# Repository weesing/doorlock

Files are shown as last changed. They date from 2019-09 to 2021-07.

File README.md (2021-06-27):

# Introduction
This project contains the Arduino Lock module program for the Door Lock.
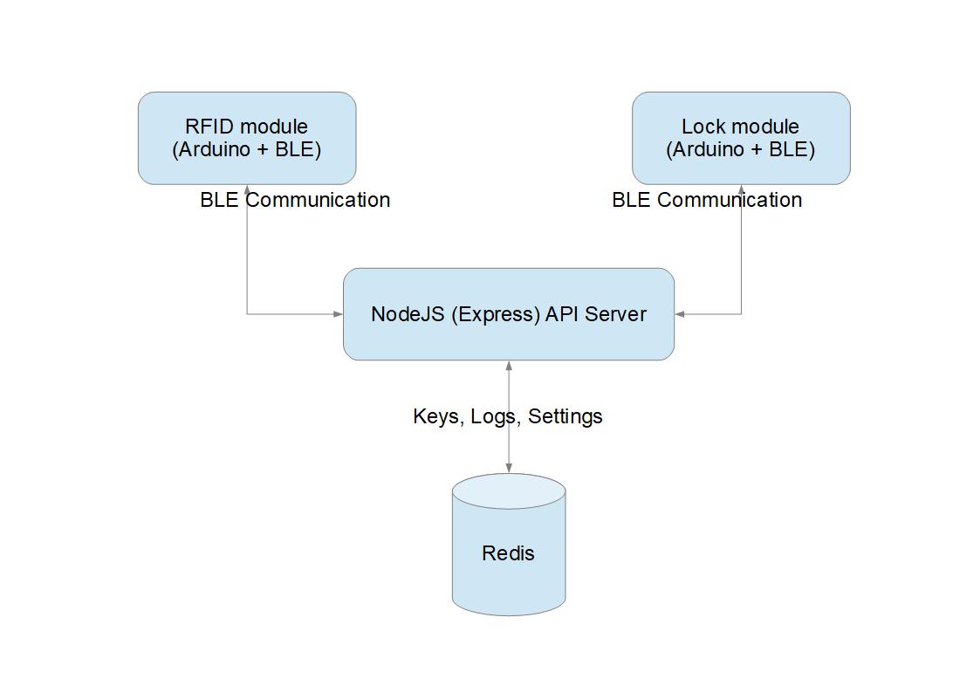
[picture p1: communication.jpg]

| Git Repository | Module |
|--|--|
| https://github.com/weesing/doorlock | This repository.
| https://github.com/weesing/doorlock_rpi | NodeJS API Server connected with main module to control different aspects of the main module, can be executed on Raspberry Pi.
| https://github.com/weesing/doorlock_rfid | RFID module for scanning RFID tags.

- The API server and module components are used for complementing the main module.
- This module should be able to function without the need for other modules.
- All aforementioned modules communicate by means of BLE.
> Note: This means if you want to construct all related modules, the Arduino used must have a BLE module or a BLE-Nano.

## Example Implementation
https://www.reddit.com/r/arduino/comments/o8vpap/have_been_a_lurker_in_this_sub_for_a_long_time/

# Required Arduino libraries
- `Adafruit GFX`
- `Adafruit SSD1306`

## Installing required libraries
- Go to Arduino IDE
- Under `Tools` -> `Library Manager`
- Search for `Adafruit GFX` and `Adafruit SSD1306`
- Click on `Install`

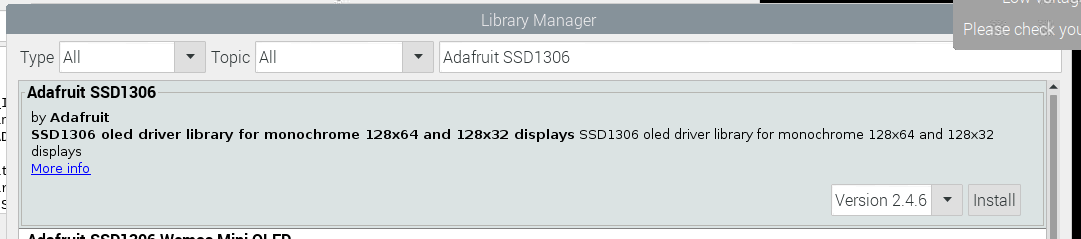
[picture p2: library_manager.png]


# Components Used
| Component | Power Requirements | Usage
| -- | -- | -- |
7.5v Power Supply or Battery Pack equivalent | N/A | Power supply
BLE-Nano (Arduino) | 6v | Main controller
MG995 Continuous Servo | 7.5v (direct from power supply) | Main servo for turning the door knob
SG90S Metal Pinion | 6v | Linear movement to engage/disengage main servo to/from actual door knob
128x64 OLED SSD1306 | 6v | Controller display
ADXL335 Accelerometer | 6v | Determines the lock status of the door knob
Buck Convertor | N/A | To step down to 6V

> Refer to `defines.h` to know which pins are used.

> Note: ALL servos must have ground back to the Arduino for the data from Arduino to flow back.

# Secrets
- A `secret_defines.h` should be created in the `DoorLock` directory (alongside `DoorLock.ino` file).
- A sample header file can be found in `secret_defines.sample.h`.
- The header file contains a definition named `SECRET_KEY`. This is used when giving the command `<lock>` through BLE (see `bleLoop()`)
> You can omit this if you are not communicating with the main module through BLE (either through the API server module or through a mobile app).

# References
## Pin Reference
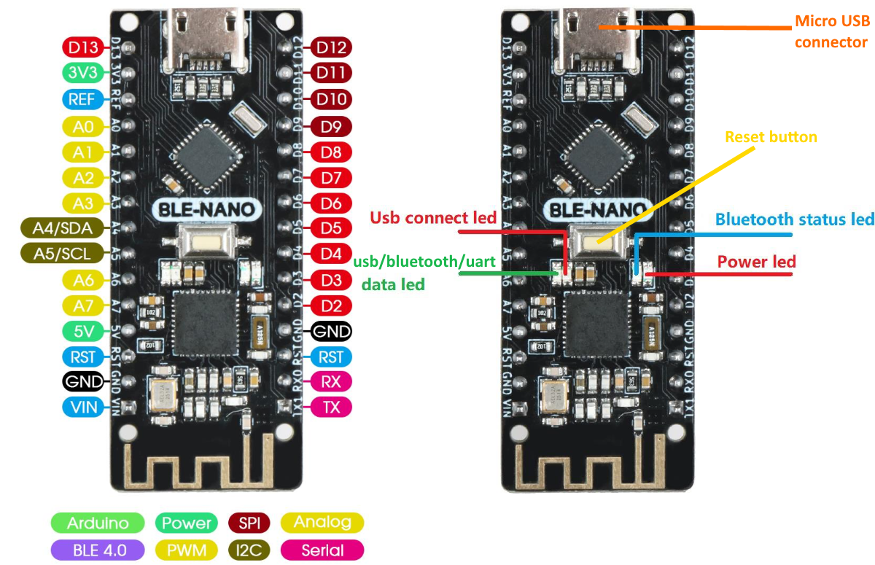
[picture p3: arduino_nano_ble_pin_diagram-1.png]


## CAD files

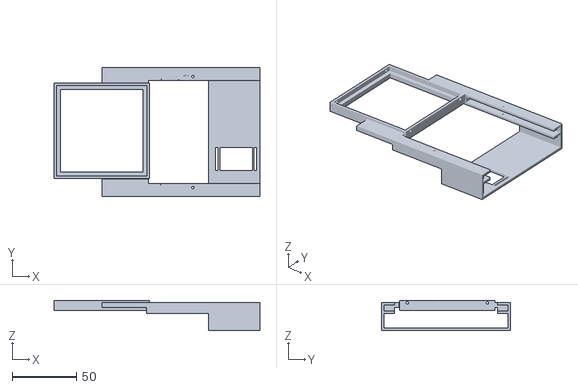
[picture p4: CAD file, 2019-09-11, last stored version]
models/stls/MainHousing.stl
160.6 x 100.5 x 23.6

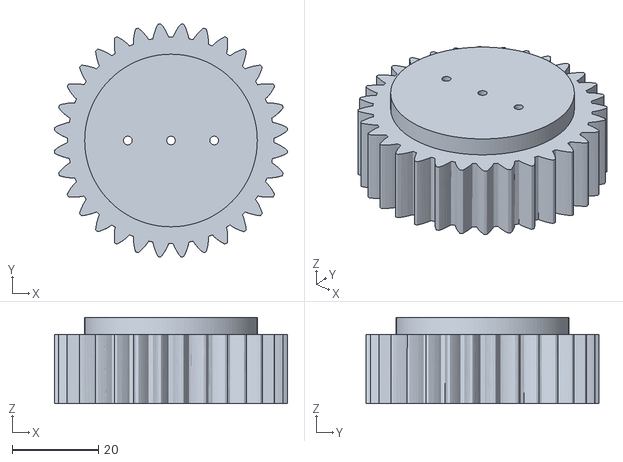
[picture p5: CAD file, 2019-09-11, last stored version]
models/stls/MainGear.stl
54.0 x 54.0 x 20.0

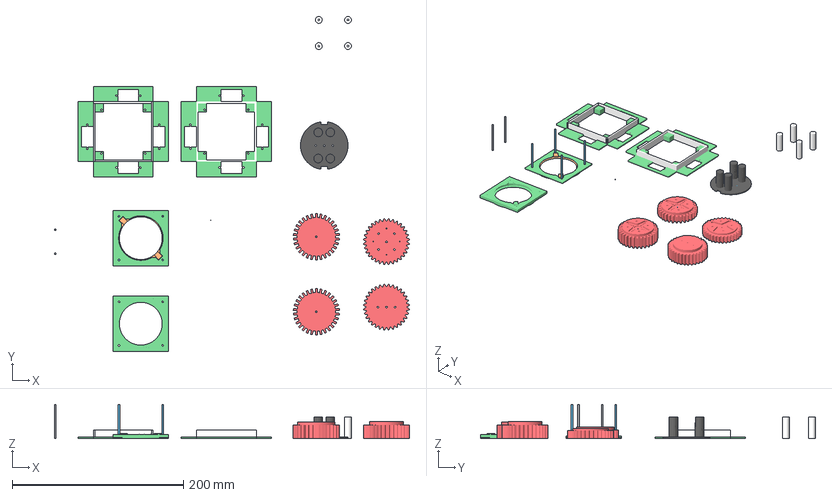
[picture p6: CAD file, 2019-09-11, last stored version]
models/DoorLock.3mf
415.2 x 391.6 x 40.0 mm

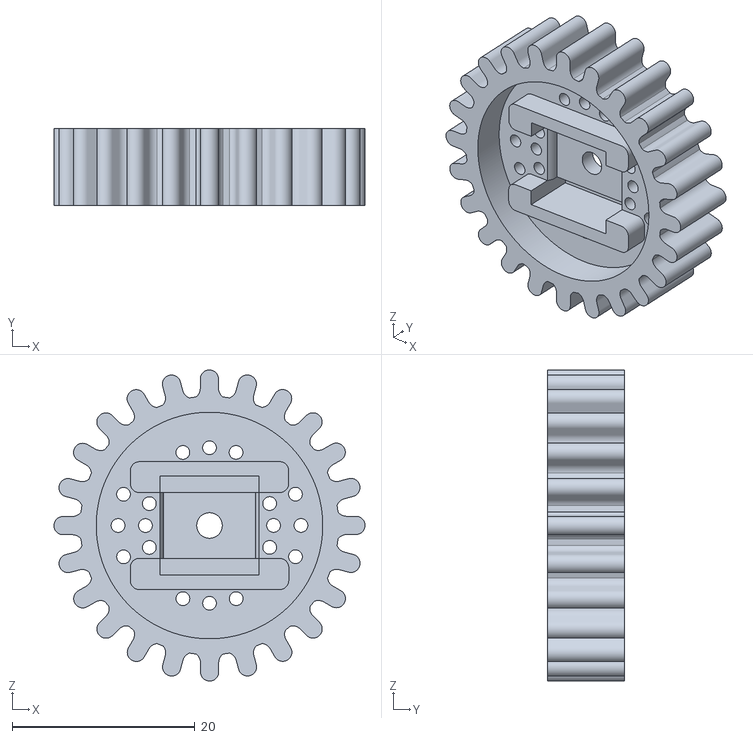
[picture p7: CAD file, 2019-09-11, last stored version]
models/gears/Linear_Servo_HiTEC_HS-645MG_/files/LINEAR_SERVO_017_2p8_square_horn_gear.stl
34.0 x 8.40 x 34.0

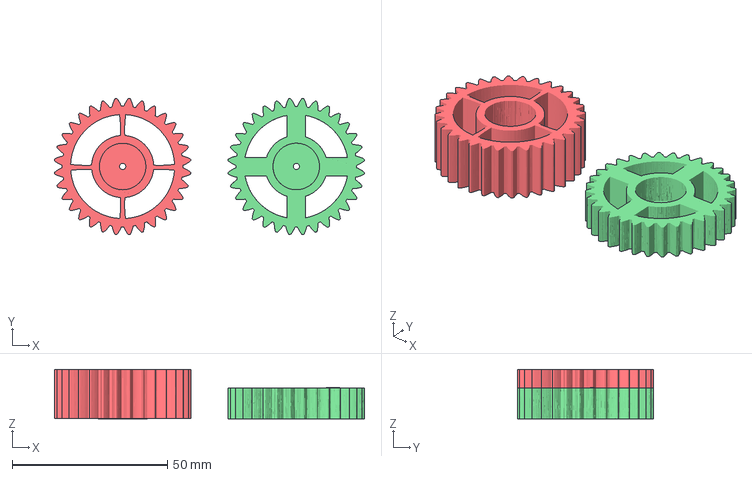
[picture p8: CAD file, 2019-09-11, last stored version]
models/gears/pocket-gears-gear-small.3mf
100.0 x 44.0 x 16.0 mm

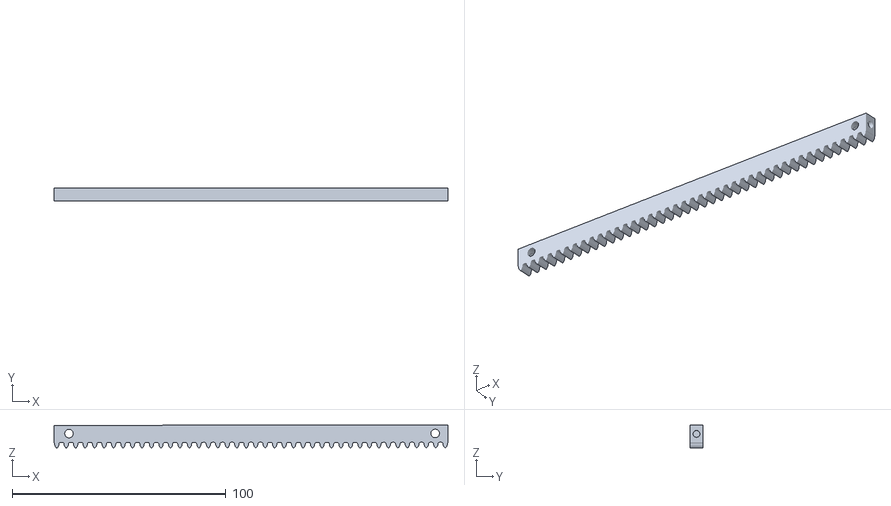
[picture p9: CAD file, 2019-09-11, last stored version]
models/gears/Linear_Servo_HiTEC_HS-645MG_/files/LINEAR_SERVO_017_long_arm.stl
184.1 x 6.00 x 10.7

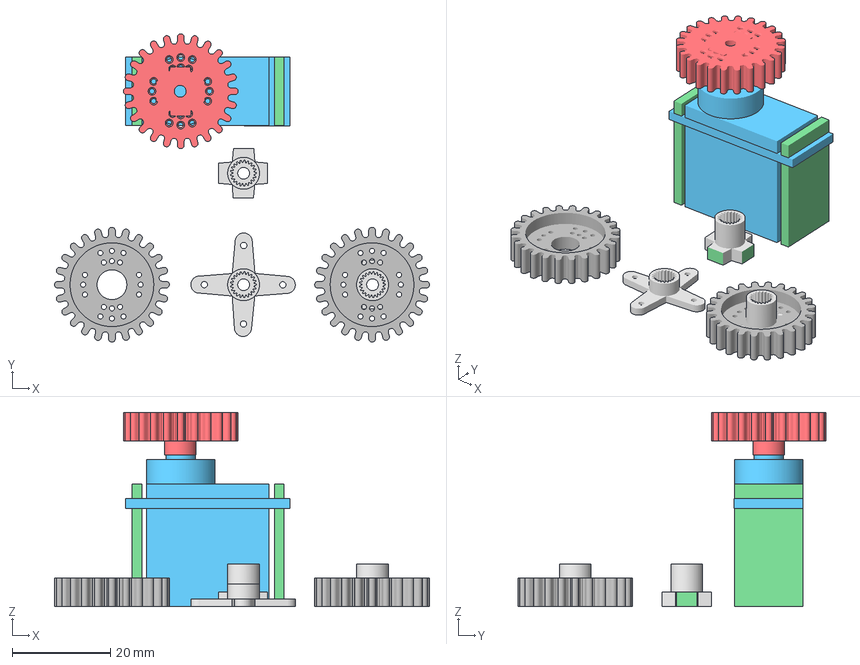
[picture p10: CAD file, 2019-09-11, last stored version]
models/gears/miniservomount.3mf
76.5 x 62.9 x 39.6 mm

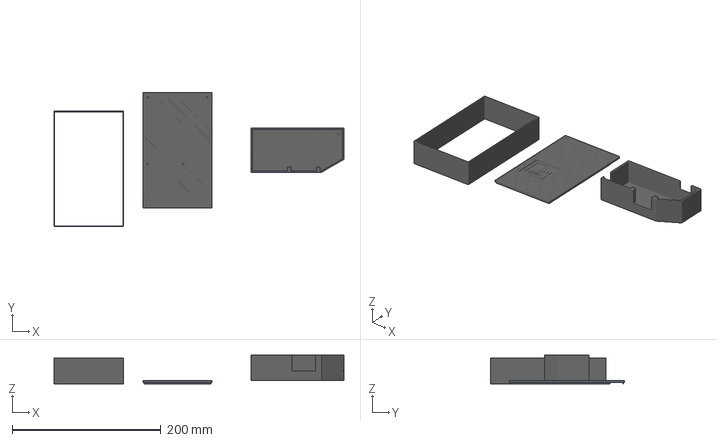
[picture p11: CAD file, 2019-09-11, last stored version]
models/SendToPrint.3mf
390.3 x 180.6 x 38.5 mm

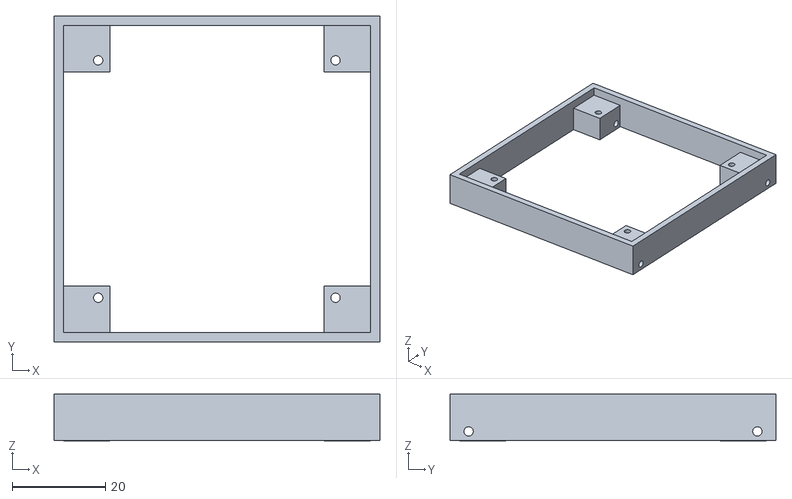
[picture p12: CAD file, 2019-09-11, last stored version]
models/stls/PlateSupport.stl
70.0 x 70.0 x 10.0

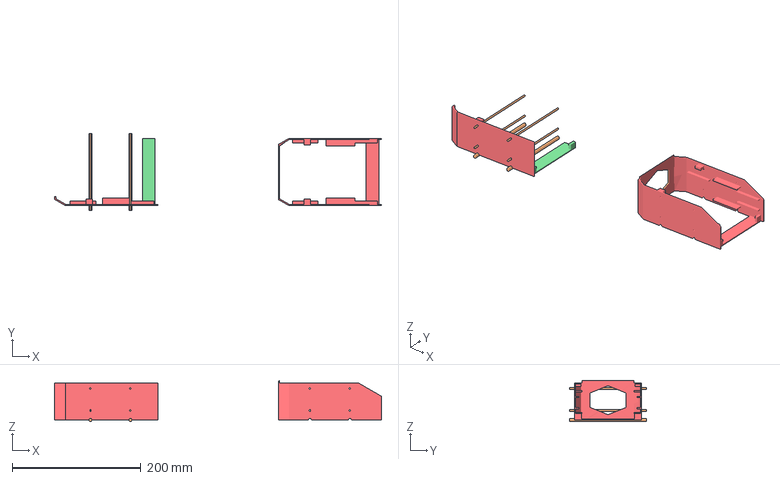
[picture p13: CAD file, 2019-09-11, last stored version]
models/dev.3mf
508.0 x 120.0 x 64.2 mm

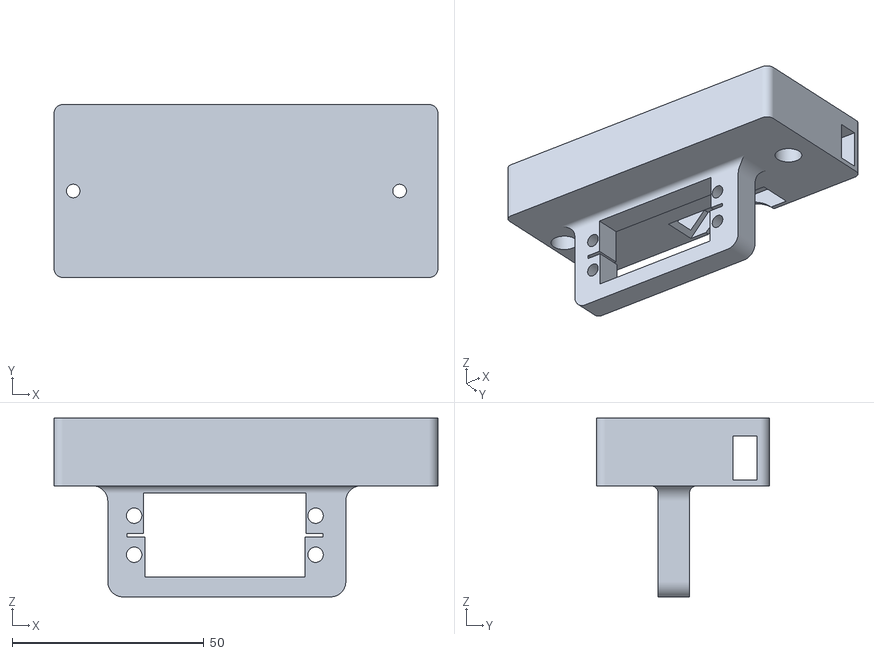
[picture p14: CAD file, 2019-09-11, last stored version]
models/gears/Linear_Servo_HiTEC_HS-645MG_/files/LINEAR_SERVO_017_FIXTURE_ext_clr.stl
100.0 x 45.1 x 46.6

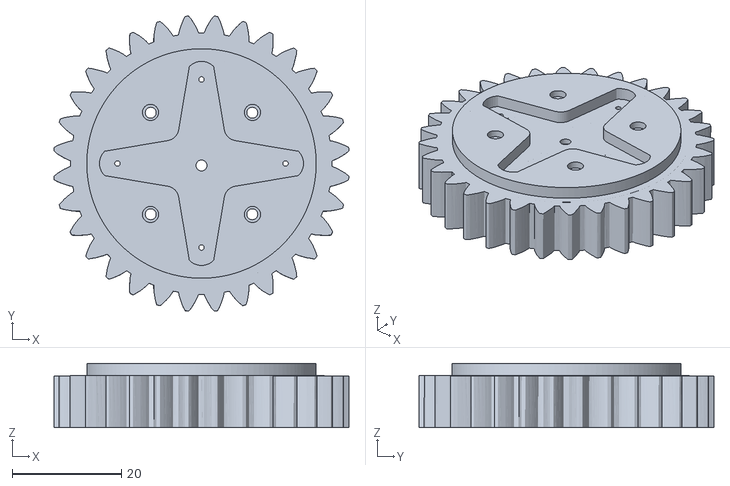
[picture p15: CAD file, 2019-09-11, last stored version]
models/stls/ServoGear.stl
54.0 x 54.0 x 11.8

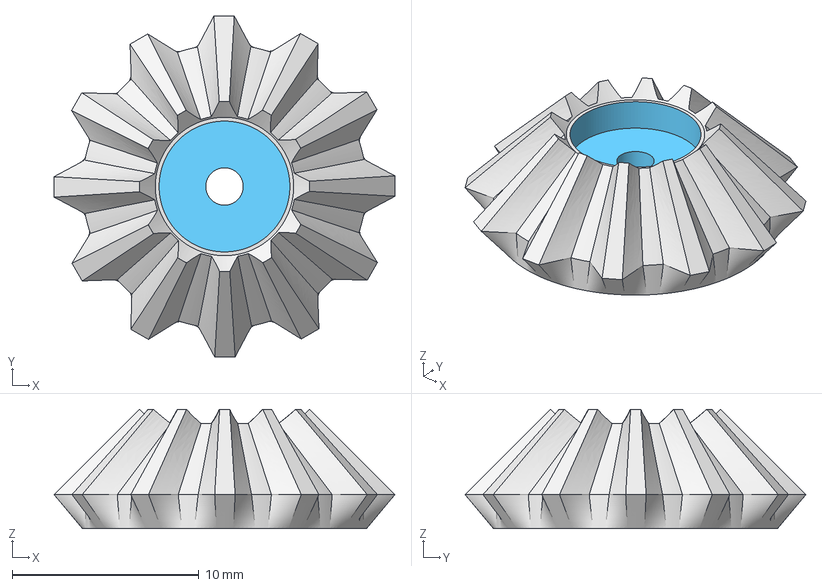
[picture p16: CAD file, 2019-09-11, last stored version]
models/gears/spline-gears.3mf
18.3 x 18.3 x 6.39 mm

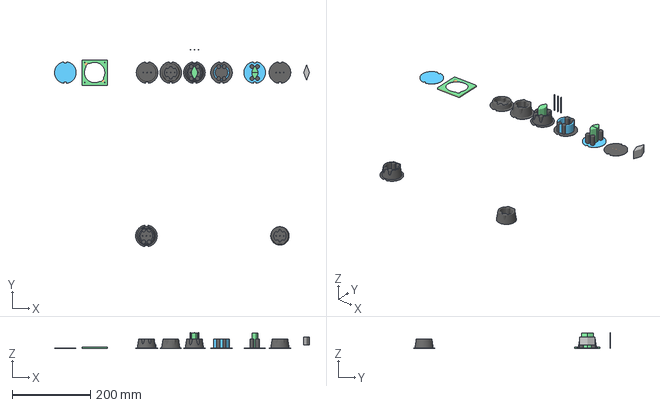
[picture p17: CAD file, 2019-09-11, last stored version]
models/Plate.3mf
652.0 x 504.6 x 42.0 mm

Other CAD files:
models/stls/SG90ServoBracket.stl
models/ControllerHousing.3mf
models/gears/Linear_Servo_HiTEC_HS-645MG_/files/LINEAR_SERVO_017_8p4mmGearThickness_1p47.stl
models/gears/parametric_involute_gear_v5.0_2.3mf
models/2dofjoint.3mf
models/BatteryHousing.3mf
models/ControllerHousing1.3mf
models/DoorLock_Prototype_HandKnob.3mf
models/DoorLock_Prototype_Plate.3mf
models/Gearset.3mf
models/Knob.3mf
models/PlateHousing.3mf
models/RFIDHousing.3mf
models/deprecated/DoorLock_Prototype_Arm.3mf
models/deprecated/DoorLock_Prototype_ServoArm.3mf
models/gears/Linear_Servo_HiTEC_HS-645MG_/files/LINEAR_SERVO_017_LINEAR_ARM_SCREW_HOLES.stl
models/gears/parametric_involute_gear_v5.0.3mf
models/gears/parametric_involute_gear_v5.0_1.3mf
models/stls/ArmsPlate.stl
models/stls/PlateHousing.stl
models/stls/ServoHousing.stl

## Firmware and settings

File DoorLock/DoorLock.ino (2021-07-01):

////////////////////////////////////////////// All required libraries
#include <Servo.h>
#include <Wire.h>
#include <SPI.h>
#include <Adafruit_GFX.h>
#include <Adafruit_SSD1306.h>

#include "defines.h"
#include "secret_defines.h"

////////////////////////////////////////////// End required libraries

void applyLockIntent(int intent)
{
  g_intentState = intent;
  if (g_currState == intent)
  {
    Serial.println(F("LCK_IGNORE"));
    return;
  }

  switch (intent)
  {
  case LOCKED:
    Serial.println(F("locking"));
    g_intentState = LOCKED;
    g_currSeqStage = SEQUENCE_INIT;
    break;
  case UNLOCKED:
    Serial.println(F("unlocking"));
    g_intentState = UNLOCKED;
    g_currSeqStage = SEQUENCE_INIT;
    break;
  }
}

void buttonLoop() {
  if (g_currTime - buttonLastTime < BUTTON_MS) {
    return;
  }

  if (g_currSeqStage != SEQUENCE_IDLE) {
    return;
  }

  buttonLastTime = g_currTime;
  if (buttonCoolingDown) {
    if (g_currTime - pressedCooldownLastTime > PRESSED_COOLDOWN_MS) {
      Serial.println(F("BTN_CD_EXP"));
      buttonCoolingDown = false;
    }
    else {
      return;
    }
  }
  else {
    int btnPressed = digitalRead(PIN_LOCK_BUTTON);
    if (btnPressed == HIGH) {
      buttonCoolingDown = true;
      pressedCooldownLastTime = g_currTime;
      if (g_currState == LOCKED) {
        Serial.println(F("Btn unlock"));
        applyLockIntent(UNLOCKED);
      }
      else {
        Serial.println(F("Btn lock"));
        applyLockIntent(LOCKED);
      }
    }
  }
}

bool moveLinearServo()
{
  if (g_currTime - servoLinearLastTime < g_SERVO_LINEAR_MS) {
    return false;
  }
  
  servoLinearLastTime = g_currTime;
  if (servoLinearArmCurr < servoLinearArmTarget) {
    if (servoLinearArmTarget - servoLinearArmCurr <= g_SERVO_LINEAR_STEP) {
      servoLinearArmCurr = servoLinearArmTarget;
    }
    else {
      servoLinearArmCurr += g_SERVO_LINEAR_STEP;
    }
    servoLinearArm.write(servoLinearArmCurr);
  }
  else {
    if (servoLinearArmCurr - servoLinearArmTarget <= g_SERVO_LINEAR_STEP) {
      servoLinearArmCurr = servoLinearArmTarget;
    }
    else {
      servoLinearArmCurr -= g_SERVO_LINEAR_STEP;
    }
    servoLinearArm.write(servoLinearArmCurr);
  }
  return servoLinearArmCurr == servoLinearArmTarget;
}

int readADXL()
{
  analogReference(EXTERNAL);
  uint8_t readCount = 0;
  int total = 0;
  for (readCount = 0; readCount < g_ADXL_READ_COUNT; ++readCount) {
    int curr = analogRead(PIN_ADXL);
    total += curr;
  }
  return total / g_ADXL_READ_COUNT;
}

void performSequenceActions()
{
  switch (g_currSeqStage)
  {
  case SEQUENCE_IDLE:
    break;
  case SEQUENCE_INIT:
    servoLinearArmTarget = g_SERVO_LINEAR_ENGAGED_DEG;
    g_currSeqStage = SEQUENCE_ENGAGE; // go to next stage immediately on next loop.
    servoLinearArm.attach(PIN_SERVO_LINEAR, 530, 2600);
    servoRotateArm.attach(PIN_SERVO_MAIN, 530, 2600);
    Serial.println(F("ENGAGE"));
    break;
  case SEQUENCE_ENGAGE:
    if (moveLinearServo())
    {
      g_currSeqStage = SEQUENCE_START_ACTION;
      Serial.println(F("START_ACTION"));
    }
    break;
  case SEQUENCE_START_ACTION:
    if (g_intentState == LOCKED) {
      gServoCurrFreq = g_SERVO_LOCK_FREQ;
      servoRotateArm.writeMicroseconds(g_SERVO_LOCK_FREQ);
    }
    else if (g_intentState == UNLOCKED) {
      gServoCurrFreq = g_SERVO_UNLOCK_FREQ;
      servoRotateArm.writeMicroseconds(g_SERVO_UNLOCK_FREQ);
    }
    g_currSeqStage = SEQUENCE_ACTION;
    Serial.println(F("ACTION"));
    break;
  case SEQUENCE_ACTION:
    if (g_currState == g_intentState) {
      gServoCurrFreq = g_SERVO_IDLE_FREQ;
      servoRotateArm.writeMicroseconds(g_SERVO_IDLE_FREQ);
      delay(100);
      servoRotateArm.detach();
      g_currSeqStage = SEQUENCE_DISENGAGE;
      Serial.println(F("DISENGAGE"));
      servoLinearArmTarget = g_SERVO_LINEAR_DISENGAGED_DEG;
      // delay to let linear arm have more current
      delay(g_SERVO_END_DELAY);
    }
    break;
  case SEQUENCE_DISENGAGE:
    if (moveLinearServo())
    {
      g_currSeqStage = SEQUENCE_END;
      Serial.println(F("END"));
      // delay a bit to let linear arm settle.
      delay(g_SERVO_LINEAR_END_DELAY);
      servoLinearArm.detach();
    }
    break;
  case SEQUENCE_END:
    g_currSeqStage = SEQUENCE_IDLE;
    Serial.println(F("IDLE"));
    break;
  }
}

void reconcileLockState()
{
  int yRot = readADXL();
  g_currKnobAngle = yRot;
  if (g_currState == UNLOCKED && g_currKnobAngle >= g_LOCKED_MIN_ANGLE)
  {
    Serial.println(F("CHG_LCK"));
    g_currState = LOCKED;
    servoRotateArm.writeMicroseconds(g_SERVO_IDLE_FREQ);
  }
  else if (g_currState == LOCKED && g_currKnobAngle <= g_UNLOCKED_MAX_ANGLE)
  {
    Serial.println(F("CHG_XLCK"));
    g_currState = UNLOCKED;
    servoRotateArm.writeMicroseconds(g_SERVO_IDLE_FREQ);
  }
}

void reconcileOLEDDisplay()
{
  int logoX = 8;
  int logoY = 15;
  int textX = 28;
  int textY = logoY - 5;
  int locX = 0;
  int locY = logoY - (ICON_BMP_HEIGHT / 2);

  display.clearDisplay();

  display.setTextSize(1);
  display.setTextColor(WHITE);
  
  unsigned char *bmp;
  String lockStateString;
    
  if (g_DEBUG_DISPLAY != 0) {
    locX = logoX - (ICON_BMP_WIDTH / 2);
  } else {
    locX = (SCREEN_WIDTH / 2) - (ICON_BMP_WIDTH / 2);
    locY += 4;
    textX = 20;
    textY = locY + 38;
  }

  if (g_currState == LOCKED)
  {
    if (g_DEBUG_DISPLAY == 0) {
      display.drawCircle(SCREEN_WIDTH / 2 - 1, logoY + 6, ICON_BMP_WIDTH, SSD1306_WHITE);
      textX = 32;
    }
    display.drawBitmap(
        locX,
        locY,
        lock_bmp, ICON_BMP_WIDTH, ICON_BMP_HEIGHT, 1);
    lockStateString = "LOCKED";
  }
  else
  {
    display.drawBitmap(
        locX,
        locY,
        unlock_bmp, ICON_BMP_WIDTH, ICON_BMP_HEIGHT, 1);
    lockStateString = "Unlocked";
  }
  display.setTextSize(2);
  display.setCursor(textX, textY);
  display.println(lockStateString);

  if (g_DEBUG_DISPLAY != 0) {
    int yRot = readADXL();
    display.setTextSize(1);
    display.setCursor(0, logoY + 14);
    display.print(F("States "));
    display.print(g_currState);
    display.print(F(" - "));
    display.println(g_intentState);
    display.print(F("Stage "));
    display.print(g_currSeqStage);
    display.print(F("  Knob "));
    display.println(g_currKnobAngle);
    display.print(F("Linear "));
    display.print(servoLinearArmCurr);
    display.print(F(" to "));
    display.println(servoLinearArmTarget);
    display.print(F("Servo "));
    display.println(gServoCurrFreq);
  }
  
  display.dim(false);

  display.display();
}

void printSettingsCommand(const String command, const String payload) {
  Serial.print(F("SET "));
  Serial.print(command);
  Serial.print(F(" = "));
  Serial.println(payload);
}

void sendValue(String key, String args) {
  Serial.print("<");
  Serial.print(key);
  Serial.print(">");
  if (key.equals("m_xlk")) {
    Serial.println(g_SERVO_UNLOCK_FREQ);
  }
  else if (key.equals("m_lk")) {
    Serial.println(g_SERVO_LOCK_FREQ);
  }
  else if (key.equals("m_idl")) {
    Serial.println(g_SERVO_IDLE_FREQ);
  }
  else if (key.equals("m_edel")) {
    Serial.println(g_SERVO_END_DELAY);
  }
  else if (key == "l_en") {
    Serial.println(g_SERVO_LINEAR_ENGAGED_DEG);
  }
  else if (key == "l_xen") {
    Serial.println(g_SERVO_LINEAR_DISENGAGED_DEG);
  }
  else if (key == "l_step") {
    Serial.println(g_SERVO_LINEAR_STEP);
  }
  else if (key == "l_ms") {
    Serial.println(g_SERVO_LINEAR_MS);
  }
  else if (key == "l_edel") {
    Serial.println(g_SERVO_LINEAR_END_DELAY);
  }
  else if (key == "a_rdct") {
    Serial.println(g_ADXL_READ_COUNT);
  }
  else if (key == "a_lk") {
    Serial.println(g_LOCKED_MIN_ANGLE);
  }
  else if (key == "a_xlk") {
    Serial.println(g_UNLOCKED_MAX_ANGLE);
  }
  else if (key == "o_dbg") {
    Serial.println(g_DEBUG_DISPLAY);
  }
}

void(* rebootFunc)(void) = 0; //reboot function @ address 0

void bleLoop()
{
  while (Serial.available())
  {
    byte b[1];
    Serial.readBytes(b, 1);
    char c = (char)(b[0]);
    if (c != '<') {
      Serial.print(c);
    }
    else {
      // ########## Read start tag ##########
      String command = Serial.readStringUntil('>');
      
      // ########## Read payload ##########
      String payload = Serial.readStringUntil(';');

      // settings commands
      if (command.startsWith("get_")) {
        command.replace("get_", "");
        sendValue(command, payload);
      }
      else if (command.equals("m_xlk")) {
        // main servo / unlock frequency
        printSettingsCommand(command, payload);
        g_SERVO_UNLOCK_FREQ = payload.toInt();
      }
      else if (command.equals("m_lk")) {
        // main servo / lock frequency
        printSettingsCommand(command, payload);
        g_SERVO_LOCK_FREQ = payload.toInt();
      }
      else if (command.equals("m_idl")) {
        // main servo / idle frequency
        printSettingsCommand(command, payload);
        g_SERVO_IDLE_FREQ = payload.toInt();
      }
      else if (command.equals("m_edel")) {
        printSettingsCommand(command, payload);
        g_SERVO_END_DELAY = payload.toInt();
      }
      else if (command.equals("l_en")) {
        // linear servo / engaged angle
        printSettingsCommand(command, payload);
        g_SERVO_LINEAR_ENGAGED_DEG = payload.toInt();
      }
      else if (command.equals("l_xen")) {
        // linear servo / disengage angle
        printSettingsCommand(command, payload);
        g_SERVO_LINEAR_DISENGAGED_DEG = payload.toInt();
      }
      else if (command.equals("l_step")) {
        // linear servo / steps
        printSettingsCommand(command, payload);
        g_SERVO_LINEAR_STEP = payload.toInt();
      }
      else if (command.equals("l_ms")) {
        // linear servo / ms
        printSettingsCommand(command, payload);
        g_SERVO_LINEAR_MS = payload.toInt();
      }
      else if (command.equals("l_edel")) {
        printSettingsCommand(command, payload);
        g_SERVO_LINEAR_END_DELAY = payload.toInt();
      }
      else if (command.equals("a_rdct")) {
        // ADXL read sample count
        printSettingsCommand(command, payload);
        g_ADXL_READ_COUNT = payload.toInt();
      }
      else if (command.equals("a_lk")) {
        // ADXL / lock angle
        printSettingsCommand(command, payload);
        g_LOCKED_MIN_ANGLE = payload.toInt();
      }
      else if (command.equals("a_xlk")) {
        // ADXL / unlock angle
        printSettingsCommand(command, payload);
        g_UNLOCKED_MAX_ANGLE = payload.toInt();
      }
      else if (command.equals("o_dbg")) {
        printSettingsCommand(command, payload);
        g_DEBUG_DISPLAY = payload.toInt();
      }
      else if (command.equals("reboot")) {
        rebootFunc();
      }
      else if (command.equals("hb")) {
//        Serial.println(F("HB ping"));
      }
      else if (command.equals("lock")) {
        Serial.print(F("LOCK "));
        if (payload.equals(SECRET_KEY)) {
          if (g_currSeqStage == SEQUENCE_IDLE) {
            Serial.println(F("Authorized"));
            // Toggle the lock
            if (g_currState == LOCKED)
            {
              applyLockIntent(UNLOCKED);
              Serial.println("<status>0");
            }
            else
            {
              applyLockIntent(LOCKED);
              Serial.println("<status>1");
            }
          }
          else {
            Serial.println(F("Device busy"));
          }
        }
        else {
          Serial.print(payload);
          Serial.println(F("Unauthorized"));
        }
      }
      else if (command.equals("status")) {
        if (g_currState == LOCKED) {
          Serial.println("<status>1");
        }
        else {
          Serial.println("<status>0");
        }
      }
    }
  }
}

// the loop function runs over and over again forever
void loop()
{
  g_currTime = millis();
  
  reconcileLockState();
  if (g_currSeqStage == SEQUENCE_IDLE) {
    buttonLoop();
  }
  else {
    performSequenceActions();
  }
  
  bleLoop();
  reconcileOLEDDisplay();
}

void requestSettings() {
  Serial.println(F("Init BLE"));
  delay(500);
  Serial.println(F("<req_lock_data>"));
  delay(500);
}

void initADXL()
{
  Serial.println(F("Init ADXL"));
  pinMode(PIN_ADXL, INPUT);
  g_currKnobAngle = readADXL();
  if (g_currKnobAngle >= g_LOCKED_MIN_ANGLE)
  {
    g_currState = LOCKED;
    g_intentState = LOCKED;
    Serial.println(F("curr-LOCKED"));
  }
  else
  {
    g_currState = UNLOCKED;
    g_intentState = UNLOCKED;
    Serial.println(F("curr-UNLOCKED"));
  }
}

void initOLED()
{
  Serial.println(F("Init OLED"));
  // SSD1306_SWITCHCAPVCC = generate display voltage from 3.3V internally
  if(!display.begin(SSD1306_SWITCHCAPVCC, SCREEN_ADDRESS)) {
    Serial.println(F("SSD1306 allocation failed"));
    for(;;); // Don't proceed, loop forever
  }

  // Clear the buffer
  display.clearDisplay();

  // Show the display buffer on the screen. You MUST call display() after
  // drawing commands to make them visible on screen!
  display.display();
  delay(2000);
    
  display.clearDisplay();

  display.setTextSize(1);
  display.setTextColor(WHITE);
  display.setCursor(0, 0);
  display.println(F("Initializing..."));

  display.dim(false);

  display.display();
  
  Serial.println(F("OLED init"));
}

void setup()
{
  Serial.begin(9600);
  
  initOLED();
  
  while (!Serial) { }
  Serial.println(F("Ser READY!"));

  delay(100);
  pinMode(PIN_LOCK_BUTTON, INPUT);
  initADXL();
  delay(100);

  Serial.println(F("Init LServo"));
  servoLinearArm.attach(PIN_SERVO_LINEAR, 530, 2600);
  servoLinearArm.write(g_SERVO_LINEAR_DISENGAGED_DEG);
  delay(1000);
  
  servoLinearArm.detach();

  Serial.println(F("Init MServo"));
  servoRotateArm.attach(PIN_SERVO_MAIN, 530, 2600);
  servoRotateArm.writeMicroseconds(g_SERVO_IDLE_FREQ);
  delay(1000);
  
  servoRotateArm.detach();

  delay(1000);
  requestSettings();

  Serial.println(F("All done"));
}

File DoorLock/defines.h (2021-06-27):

// Lock status
#define LOCKED 1
#define UNLOCKED 0
#define UNKNOWN -1

//PWM
//3, 5, 6, 9, 10, and 11
#define PIN_SERVO_MAIN 2 // MG996
#define PIN_LOCK_BUTTON 3
#define PIN_SERVO_LINEAR 4 // SG90
#define PIN_ADXL A0        // GY-61 ADXL335

///////////////////////////////// BUTTON
#define PRESSED_COOLDOWN_MS 2000
unsigned long pressedCooldownLastTime;
bool buttonCoolingDown = false;
#define BUTTON_MS 100
unsigned long buttonLastTime;

//////////////////////////////// MAIN SERVO
int g_SERVO_UNLOCK_FREQ     = 1800;
int g_SERVO_IDLE_FREQ       = 1500;
int g_SERVO_LOCK_FREQ       = 1200;
int g_SERVO_END_DELAY       = 200;
int gServoCurrFreq          = g_SERVO_IDLE_FREQ;
Servo servoRotateArm;

///////////////////////// ADXL
int g_LOCKED_MIN_ANGLE      = 580;
int g_UNLOCKED_MAX_ANGLE    = 436;
int g_ADXL_READ_COUNT = 50;
uint32_t g_currKnobAngle = -1;

//////////////////////////////// LINEAR SERVO
int g_SERVO_LINEAR_ENGAGED_DEG      = 77;
int g_SERVO_LINEAR_DISENGAGED_DEG   = 45;
int g_SERVO_LINEAR_STEP             = 4;
int g_SERVO_LINEAR_MS               = 10;
int g_SERVO_LINEAR_END_DELAY        = 1000;
Servo servoLinearArm;
uint16_t servoLinearArmTarget       = g_SERVO_LINEAR_DISENGAGED_DEG;
uint16_t servoLinearArmCurr         = g_SERVO_LINEAR_DISENGAGED_DEG;
unsigned long servoLinearLastTime = 0;

///////////////////////// BLE

///////////////////////// OLED Display
#define SCREEN_WIDTH    128
#define SCREEN_HEIGHT   64
uint8_t g_DEBUG_DISPLAY = 0;

// Declaration for an SSD1306 display connected to I2C (SDA, SCL pins)
#define OLED_RESET      -1 // Reset pin # (or -1 if sharing Arduino reset pin)
#define SCREEN_ADDRESS  0x3C ///< See datasheet for Address; 0x3D for 128x64, 0x3C for 128x32
Adafruit_SSD1306 display(SCREEN_WIDTH, SCREEN_HEIGHT, &Wire, OLED_RESET);

#define ICON_BMP_HEIGHT 22
#define ICON_BMP_WIDTH 16

static const unsigned char PROGMEM lock_bmp[] =
    {B00000000, B00000000,
     B00000000, B00000000,
     B00000000, B00000000,
     B00000000, B00000000,
     B00000111, B11100000,
     B00001100, B00110000,
     B00001000, B00010000,
     B00001000, B00010000,
     B00001000, B00010000,
     B00001000, B00010000,
     B00111111, B11111100,
     B01111111, B11111110,
     B01111111, B11111110,
     B01111100, B00111110,
     B01111100, B00111110,
     B01111110, B01111110,
     B01111110, B01111110,
     B01111110, B01111110,
     B01111111, B11111110,
     B01111111, B11111110,
     B01111111, B11111110,
     B00111111, B11111100};

static const unsigned char PROGMEM unlock_bmp[] =
    {B00000111, B11100000,
     B00001100, B00110000,
     B00001000, B00010000,
     B00001000, B00010000,
     B00001000, B00010000,
     B00001000, B00010000,
     B00000000, B00010000,
     B00000000, B00010000,
     B00000000, B00010000,
     B00000000, B00010000,
     B00111111, B11111100,
     B01111111, B11111110,
     B01111111, B11111110,
     B01111100, B00111110,
     B01111100, B00111110,
     B01111110, B01111110,
     B01111110, B01111110,
     B01111110, B01111110,
     B01111111, B11111110,
     B01111111, B11111110,
     B01111111, B11111110,
     B00111111, B11111100};

unsigned long g_currTime;

#define SEQUENCE_IDLE -1
#define SEQUENCE_INIT 0
#define SEQUENCE_RESET_ARM 1
#define SEQUENCE_ENGAGE 2
#define SEQUENCE_START_ACTION 3
#define SEQUENCE_ACTION 4
#define SEQUENCE_DISENGAGE 5
#define SEQUENCE_END 6

int8_t g_currSeqStage = SEQUENCE_IDLE;

uint8_t g_currState = UNKNOWN;
uint8_t g_intentState = UNKNOWN;

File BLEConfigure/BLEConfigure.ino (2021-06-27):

#include <SoftwareSerial.h>
#include "secret_defines.h"

SoftwareSerial BTSerial(10, 11); // RX | TX

void sendCommand(const char* command) {
  Serial.print("Sending command: >");
  Serial.println(command);
  
  BTSerial.println(command);
  delay(500);
  if (BTSerial.available())
  {
    char reply[1000];
    int i = 0;
    while (BTSerial.available())
    {
      char c = BTSerial.read();
      Serial.print(c);
      reply[i] = c;
      i += 1;
    }
    reply[i] = '\0';
    Serial.println(F("END"));
//    Serial.print(reply);
  }
}

void bleLoop() {
  while (Serial.available())
  {
    byte b[1];
    Serial.readBytes(b, 1);
    char c = (char)(b[0]);
    if (c != '<') {
      Serial.print("Unknown character received ");
      Serial.print(c);
      Serial.println("");
    }
    else {
      // ########## Read start tag ##########
      String command = Serial.readStringUntil('>');
      
      // ########## Read payload ##########
      String payload = Serial.readStringUntil(';');

      if (command.equalsIgnoreCase("setting")) {
        int separatorIndex = payload.indexOf('=');
        String key = payload.substring(0, separatorIndex);
        String value = payload.substring(separatorIndex + 1);
        Serial.print("SET ");
        Serial.print(key);
        Serial.print(" = ");
        Serial.println(value);
        
      }
      else if (command.equalsIgnoreCase("data")) {
        Serial.print("DATA ");
        Serial.println(payload);
      }
      else if (command.equalsIgnoreCase("lock")) {
        Serial.print("LOCK ");
        if (payload.equals(SECRET_KEY)) {
          Serial.println("Authorized");
        } else {
          Serial.print(payload);
          Serial.println(" <-- Unauthorized");
        }
      }
    }
  }
}

void loop() {
  bleLoop();
}

void setup()
{
  Serial.begin(9600);
  BTSerial.println("U,9600,N");
  BTSerial.begin(9600);  // HC-05 default speed in AT command more
  Serial.println("Waiting for incoming data");
}

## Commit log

2019-09-11 Removing models
    [2dofjoint.3mf, ArmsPlate.stl, BatteryHousing.3mf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]
2019-09-14 Changed ring sleep brightness to 0. Changed logic of tilt sensor.
2019-09-23 Moved some common variables for cooldown out of #define BUTTON_ENABLED. Re-enabled button.
2019-09-25 ADXL335 Accelerometer implementation
2019-10-02 Changed engaged angle, locked and unlock min/max angle. Fixed syntax error in sequence test count serial print. Fixed missing PIN_LOCK_BUTTON definition for call to pinMode for lock button when BUTTO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
    [DoorLock.ino]
2021-06-18 Added secrets header file sample
2021-06-18 Ignore lock command if sequence stage is not idle.
2021-06-18 Printing unknown commands
2021-06-18 Converting main servo #defines to variables
2021-06-26 Immediately shutting down main servo when state change.
2021-06-27 End delay settings for servos.
2021-06-27 Detach main servo before disengaging.
